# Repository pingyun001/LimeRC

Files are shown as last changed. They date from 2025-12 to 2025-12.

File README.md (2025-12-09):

# LimeRC
数字图传遥控器系统 基于NRF24L01

Digital Video Transmission Remote &amp; Receiver（Based on NRF24L01）
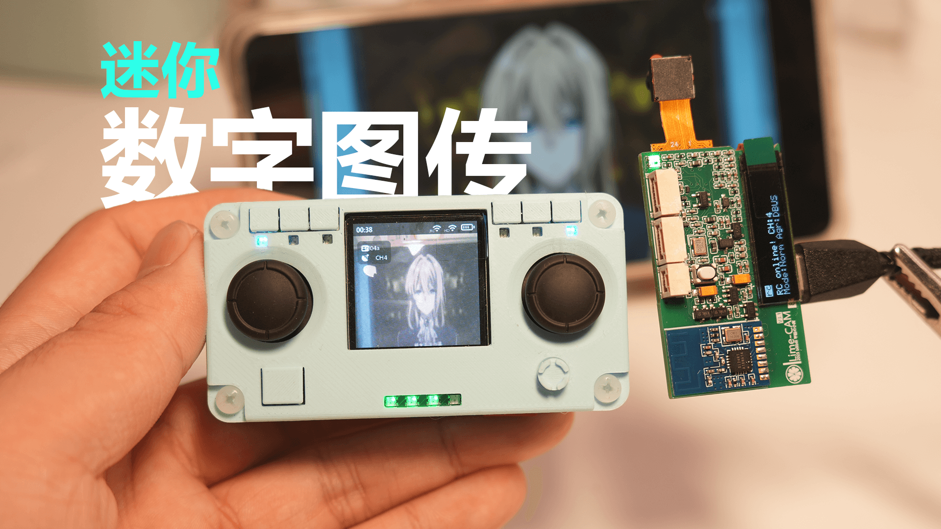
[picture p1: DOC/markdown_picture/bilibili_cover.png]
bilibili_cover


# 详细介绍
> 请跳转立创开源广场查看：
 https://oshwhub.com/phantom001/limerc3-1_release

# 如何获取仓库?

## 使用以下链接获取仓库：

> 遥控器主板程序使用了LVGL Release v9.3，通过submodule的方式引入，请确保使用git clone --recurse-submodules命令克隆仓库。

```
git clone --recurse-submodules https://github.com/pingyun001/LimeRC.git
```
如果已经克隆，可通过如下命令更新submodule：
```
git submodule init
git submodule update
```

## 固件编译

详情参考SOFTWARE文件夹

## 固件下载

推荐使用keil 5MDK 内置下载功能进行下载

若使用CubeProgrammer, 可使用ST-Link配套下载

!!注意 遥控器主板无法通过ST-Link+CubeProgrammer下载，可通过USB下载（按住BOOT键后插入USB到电脑）

# 联系作者

欢迎通过BiliBili私信：
https://space.bilibili.com/336483389

工作忙，尽量24小时内回复

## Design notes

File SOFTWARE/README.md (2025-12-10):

# 文件夹说明
- Lime_SimAgreement：仿真协议，用于测试仿真器与仿真模型的通信协议
- LimeCam_Release：图传接收机源代码
- LimeScrBoard_Release：屏幕按键子板源代码
- LimeMainBoard_Release：遥控器主板源代码
- Z-releaseHex：已编译好的Hex固件
# 编译说明
## Lime_SimAgreement仿真（非必须）
推荐使用VSCode，配置CMake环境+GCC编译
## STM32工程（必须）
- LimeCam_Release
- LimeScrBoard_Release
- LimeMainBoard_Release

推荐使用keil 5MDK编译 需安装如下芯片的keil芯片包
- STM32F0
- STM32F4
- STM32H7

相关芯片包可从keil官网下载 若找不到芯片包，可联系作者获取

推荐keil版本V5.38及以上

注意编译主板固件LimeMainBoard_Release时，需确认lvgl子模块也被克隆

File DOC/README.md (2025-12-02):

# 文件夹说明
## markdown_picture文件夹
> 照片素材，用于本仓库内markdown文件展示

## sdcard_resources文件夹
> 这些图片均由AI生成，仅用于测试机内jpeg软解码器

这些文件可放于SD卡根目录中LimeLvResources文件夹，在点击设置->存储->格式化机内存储时，程序会自动复制这些图片到图库中。

完成后，便可在图库中看到相关图像

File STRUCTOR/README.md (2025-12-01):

# 注意
软件版本为SolidWorks 2025
请使用2025及以上版本打开

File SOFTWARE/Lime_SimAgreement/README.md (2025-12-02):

# 文件夹说明
> 此工程用于软件仿真编解码器

推荐使用VSCode + CMAKE环境编译运行

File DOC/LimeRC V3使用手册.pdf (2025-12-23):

# LimeRC V3使用手册

系统概述：

遥控器操作说明：

遥控器按键说明：

开机说明：

APP选择器说明：

RC遥控APP：

图库APP：

接收机APP：

摇杆校准APP：

设置APP：

接收机 子选项

时间 子选项

屏幕 子选项

存储 子选项

关于 子选项：

接收机操作说明：

LED状态总结：

固件更新：

遥控器主板固件更新：

图传接收机固件更新：

### Mult-Bus输出：

输出电平：

电平正常：

电平取反：

输出协议：

DBUS：

### SBUS：

PP：

DEBUG:

QA：

连接逻辑？

续航&充电？

遥控器卡死了怎么办？

关于

系统由遥控器，接收机两部分组成

# 系统概述：

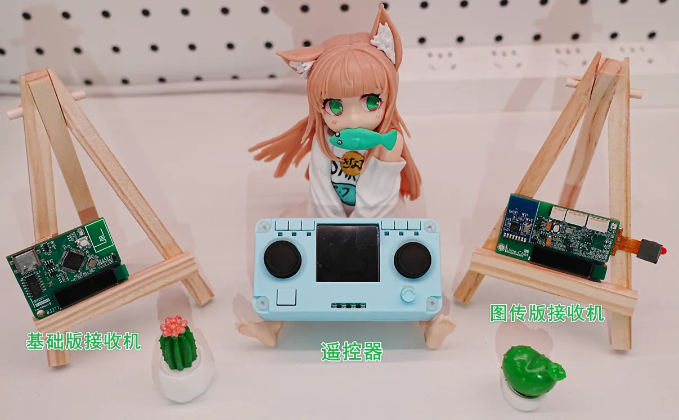
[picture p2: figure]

# 遥控器操作说明：

## 遥控器按键说明：

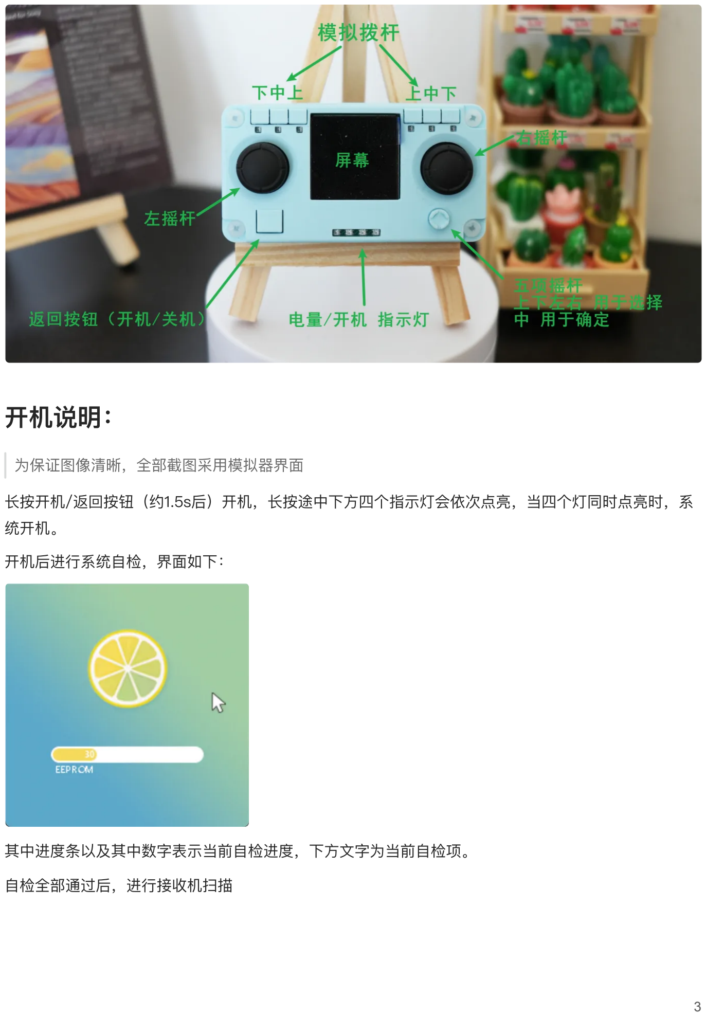
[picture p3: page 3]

长按开机/返回按钮（约1.5s后）开机，长按途中下方四个指示灯会依次点亮，当四个灯同时点亮时，系

统开机。

开机后进行系统自检，界面如下：

其中进度条以及其中数字表示当前自检进度，下方文字为当前自检项。

自检全部通过后，进行接收机扫描

## 开机说明：

为保证图像清晰，全部截图采 | 用模拟器界 | 面

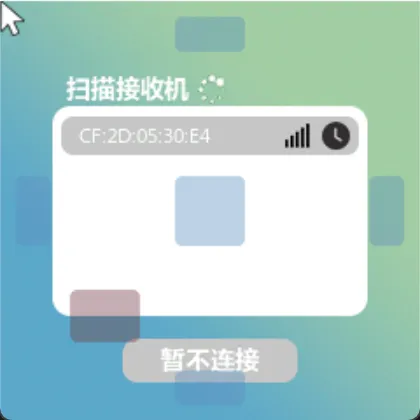
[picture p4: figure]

此界面中可通过五项摇杆“上”、“下”选择需要的接收机，“中”进行选择。

连接完成后点击下一步（后续版本支持多接收机）

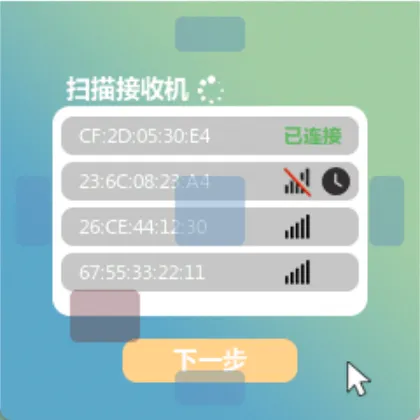
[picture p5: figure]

进入LRC主界面，

顶部状态栏依次为当前时间，遥控器数据下发信号质量，图像回传信号质量，遥控器电量

左侧悬浮窗为接收机名称，接收机所在物理信道。

当前界面中，短按五向摇杆“中”可隐藏UI，短按“右”，可进行拍照（需要连接图传接收机）

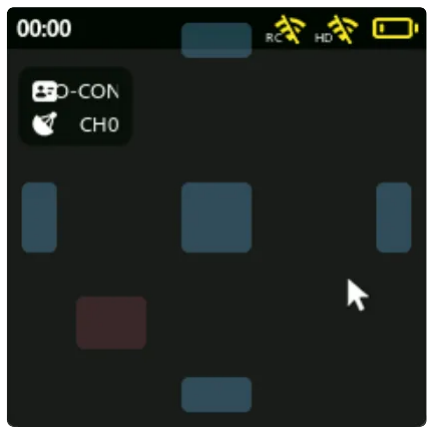
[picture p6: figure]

缺已连接实物图。

长按返回键可退出当前APP：

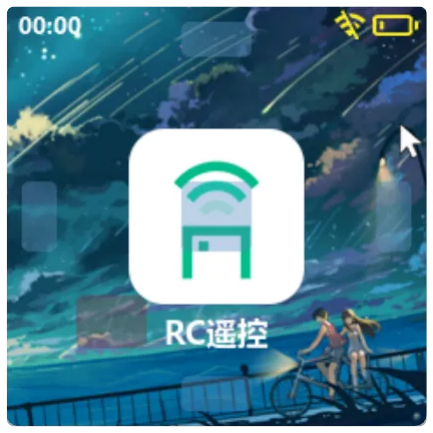
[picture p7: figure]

上述APP为RC遥控APP

APP选择器如下，上方状态栏依次为当前系统时间，遥控器信号质量，遥控器电池信息。

## APP选择器说明：

未连接

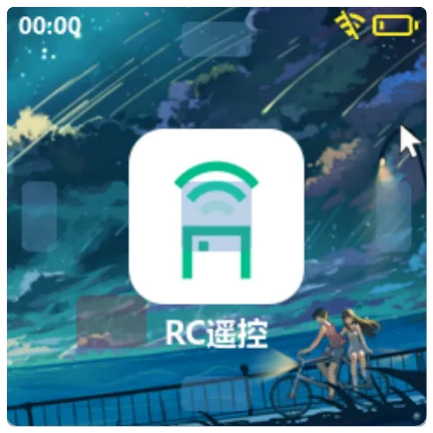
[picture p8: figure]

在该界面下，按下五向摇杆中的“左”或“右”切换APP，按下“中”进入当前APP

V3版本中，APP一共有如下五个：

APP功能如下：

RC遥控：日常操作的主界面，用于观察接收机回传图像，拍照

图库：可以浏览拍到的图像，以及对图像进行删除操作

接收机：为遥控器启动时的对频界面，可以看到当前接收机的连接信息，以及取消配对/配对新接收

机

摇杆校准：校准摇杆零点和极值点，用以补偿摇杆体质不同导致的误差

设置：对遥控器各项功能参数进行设置，详见下文

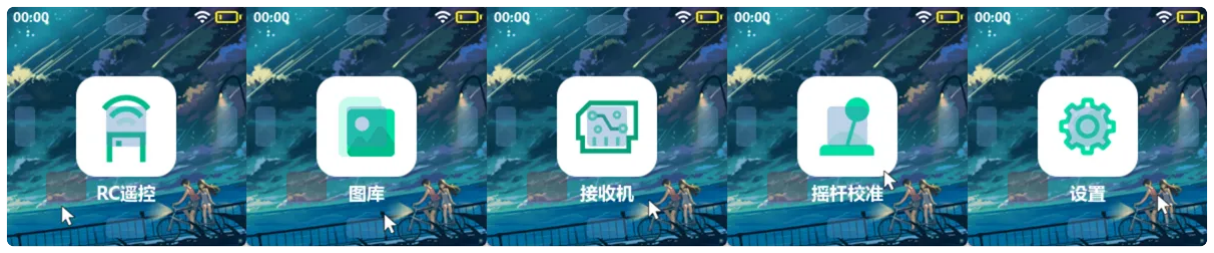
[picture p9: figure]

该APP功能已在上一章 开机说明 中描述，详情看相关章节。

选择&打开图像：

在该APP中，可通过五向摇杆“上”“下”选择图像，点击“中”打开图像，

关闭图像：

在打开图像状态，点击返回关闭图像。

删除图像：

在未打开图像阶段，单击“左”可弹出删除按钮，再次单击“中”，可删除该图像。再次单击“左”，可隐藏

删除按钮。

●

●

●

●

●

### RC遥控APP：

### 图库APP：

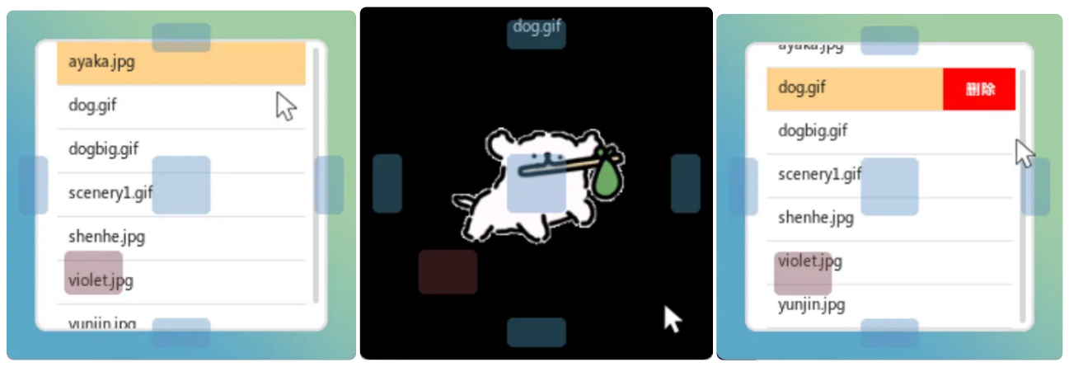
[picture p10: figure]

该APP功能已在上一章 开机说明 中描述，详情看相关章节。

该APP用于自动测量摇杆的中值、死区和边界值，打开后如下：

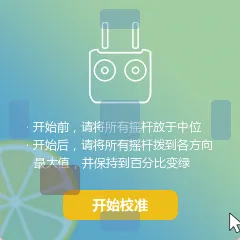
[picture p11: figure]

通过五项摇杆“中”点击开始校准按钮，进入第二界面，

进入第二界面后等待2秒（此两秒用于自动测量中位和死区），

之后将左右两侧摇杆分别推向各个方向最大值并等待2s，待进度百分数变为绿色，则该方向校准完成。

第二界面屏幕显示如下：

## 接收机APP：

## 摇杆校准APP：

！！！注意： | 一定确保两侧摇杆均处于中间位置再进 | 入第 | 二界 | 面
图像选择 | 已经打开的图像 | 图像删除

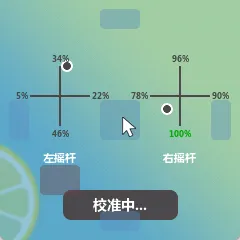
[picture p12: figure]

待完成两个摇杆共8个方向的校准后，下方按钮会变绿，此时可以退出该APP。

校准结果会自动保存到板载EEPROM。

设置APP主界面如下，可通过五向摇杆“上”“下”选择子选项，通过“中”进入子选项。

在子选项中单击返回，可退回设置APP主界面。

每个子选项中，均遵循“上”“下”选择，“中”确定，“返回”返回的逻辑，下文不再赘述。

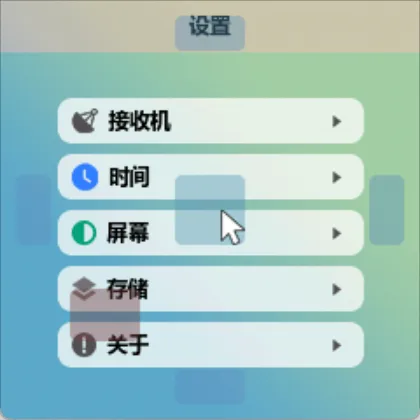
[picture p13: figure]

输出协议：可选DBUS，SBUS，PP，DEBUG。

DBUS：参考DJI DR16接收机输出协议，推荐搭配反向电平使用

### 设置APP：

## 接收机 子选项

●

○

设置APP主界面

SBUS：航模通用协议（待完善）

PP：本作者自有协议，协议帧采用不定长帧，可视化，易于解码。

DEBUG：保留

输出电平：可选正常，反向，静默。

！！！注意！！！

为防止短时期内输出大量不同协议帧到接收机，输出协议和输出电平只有在打开RC遥控APP时才更新到

接收机

另附电平输出样例：（以DBUS，摇杆全归中，三档拨杆下拨）

正常电平：

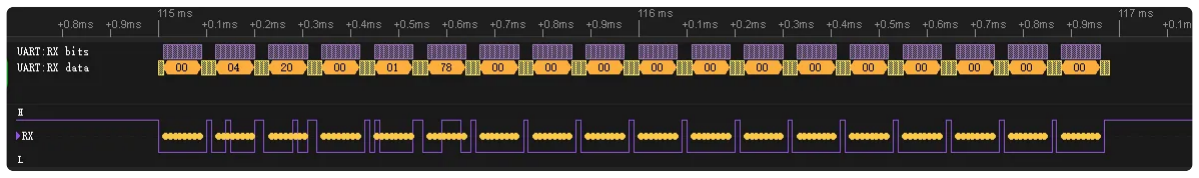
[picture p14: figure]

反向电平：

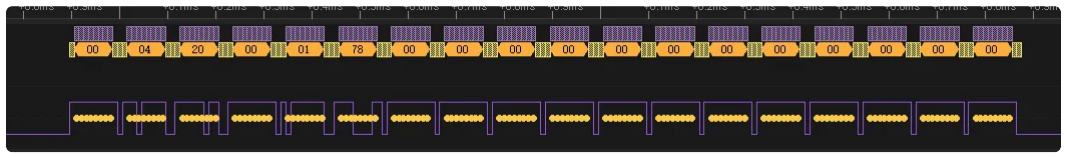
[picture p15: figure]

可设置RTC时间，该时间会用于存储图像以及文件复制时的时间，若不在意可不设置。

○

○

○

●

## 时间 子选项

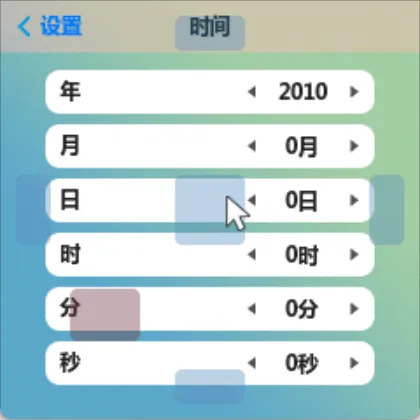
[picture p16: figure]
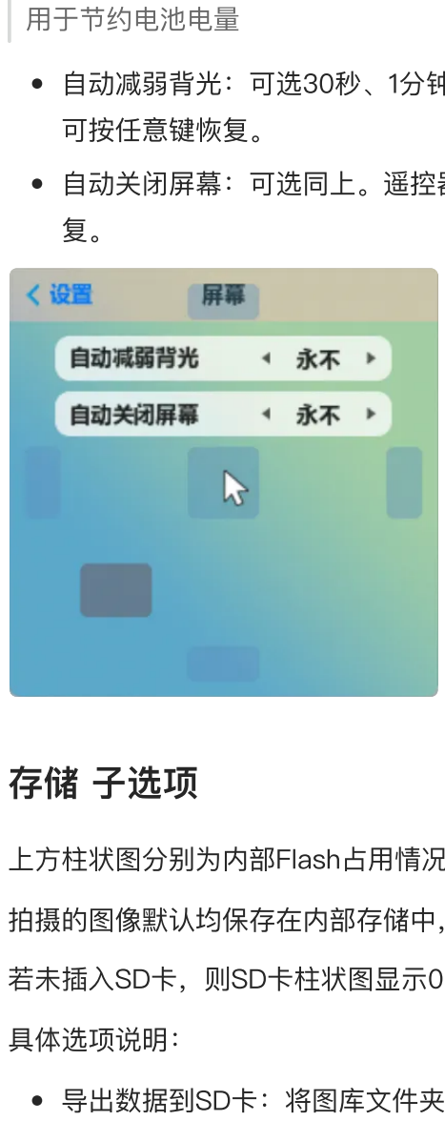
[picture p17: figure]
用于节约电池电量; 存储 子选项

自动减弱背光：可选30秒、1分钟、5分钟、永不。遥控器无操作超过相应时间后，屏幕亮度降低，

可按任意键恢复。

自动关闭屏幕：可选同上。遥控器无操作超过相应时间后，屏幕设定为最低亮度，可按任意键恢

复。

上方柱状图分别为内部Flash占用情况以及外部SD卡占用情况。

拍摄的图像默认均保存在内部存储中，可通过“导出数据到SD卡”选项导出。

若未插入SD卡，则SD卡柱状图显示0

具体选项说明：

导出数据到SD卡：将图库文件夹下的所有文件复制到SD卡。

## 屏幕 子选项

格式化机内存储：清空内部Flash中的图库文件夹。

格式化SD卡：清空SD卡并格式化为FAT32（适用于新SD卡）

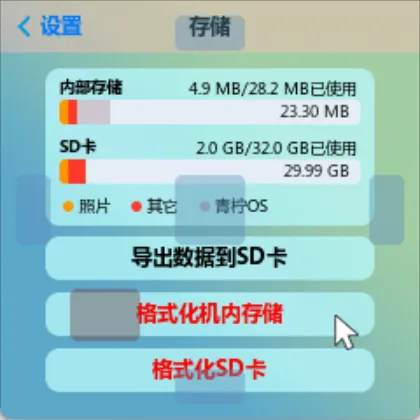
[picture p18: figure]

可查看 产品名称，软硬件版本等相关信息。

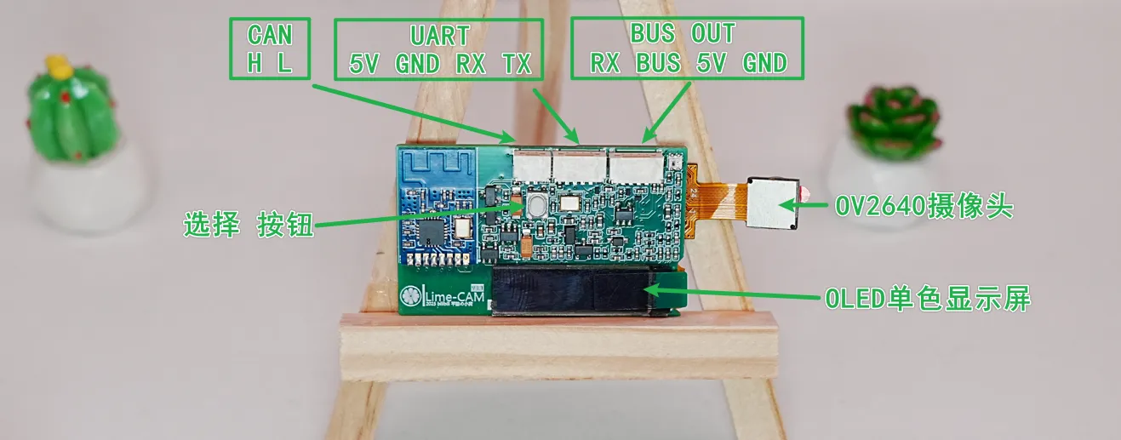
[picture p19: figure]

上电后，通过按钮可选择各个菜单/信息

在RC界面下，长按按钮，可进入配对模式，此时屏幕显示Pairing...，LED亮蓝色。

此时打开遥控器，在遥控器的接收机APP中，可以看到当前处于配对状态的接收机，并选择连接。

连接成功后，接收机亮绿灯，若中途断联，接收机亮红灯。

●

●

## 关于 子选项：

# 接收机操作说明：

蓝灯：接收机处于配对状态

红灯：接收机已有配对信息，但与遥控器断开连接

绿灯：接收机已连接遥控器

遥控器暂时需要拆卸底壳与侧壳，按下BOOT按键后插入USB，以更新固件。

电脑上需安装STM32CubeProgrammer软件：

安装后打开，按住遥控器上的BOOT按键，插入USB到电脑，并进行如下操作：

### LED状态总结：

●

●

●

# 固件更新：

## 遥控器主板固件更新：

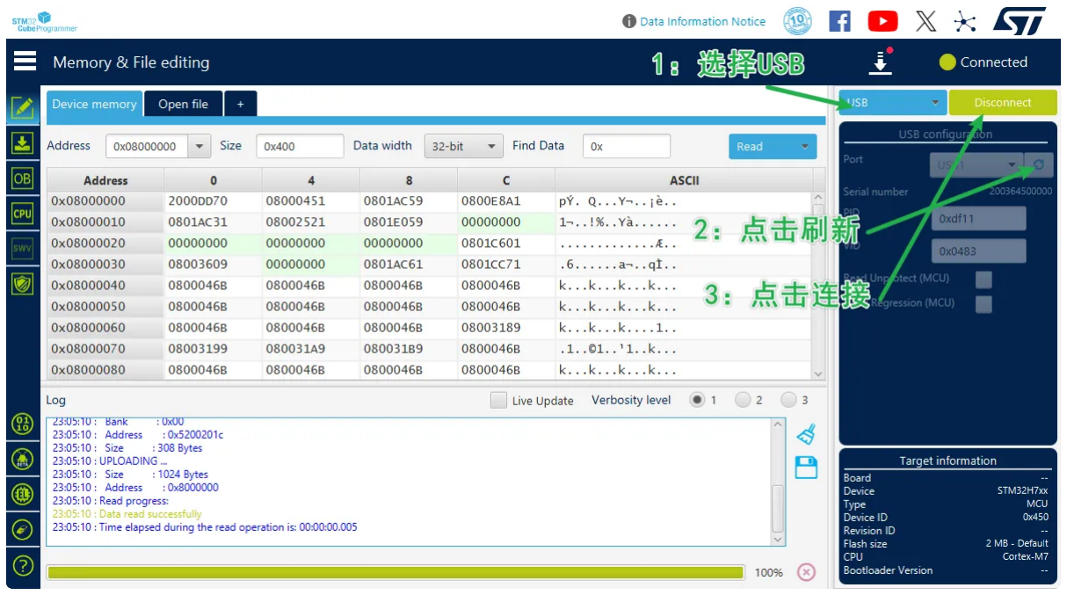
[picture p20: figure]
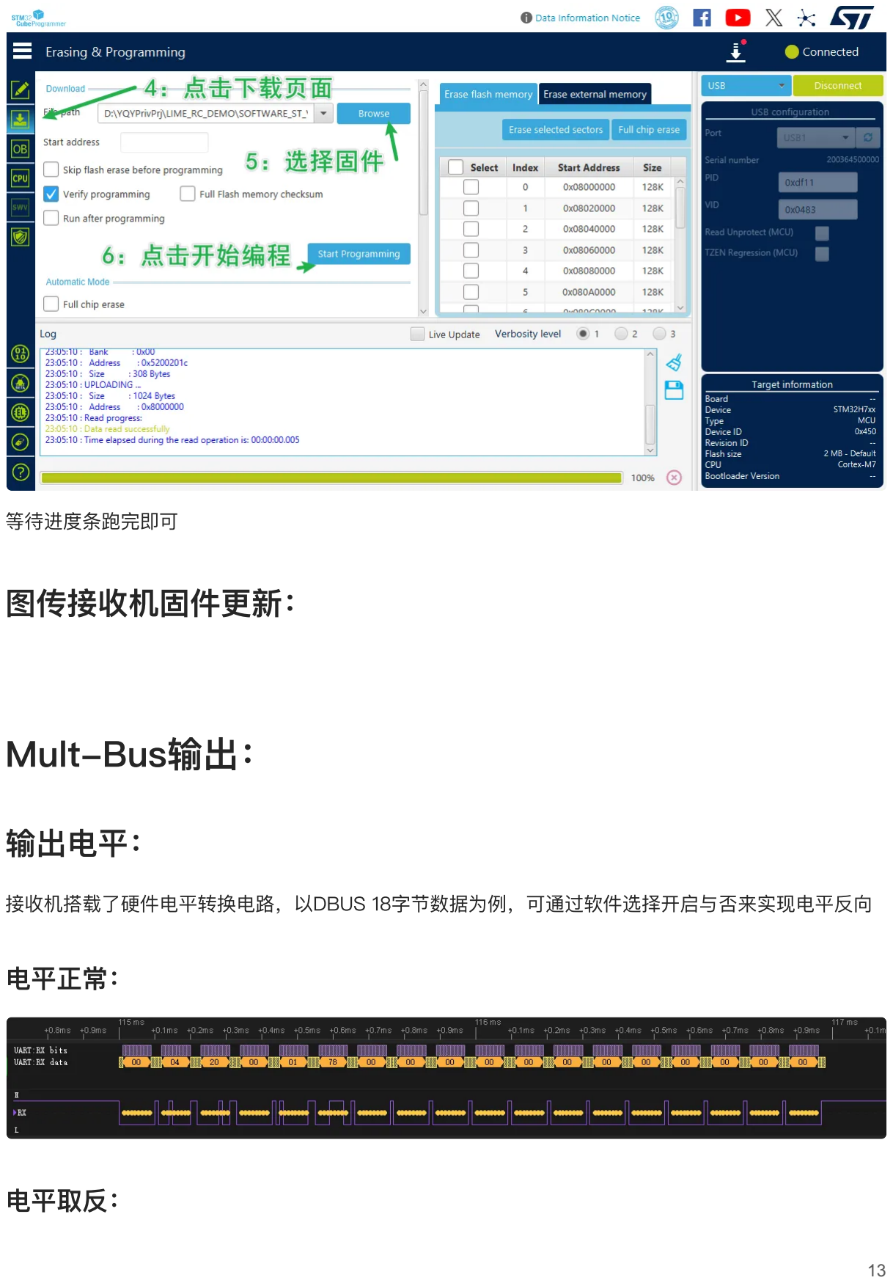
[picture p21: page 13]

等待进度条跑完即可

接收机搭载了硬件电平转换电路，以DBUS 18字节数据为例，可通过软件选择开启与否来实现电平反向

## 图传接收机固件更新：

## Mult-Bus输出：

## 输出电平：

## 电平正常：

## 电平取反：

## 输出协议：

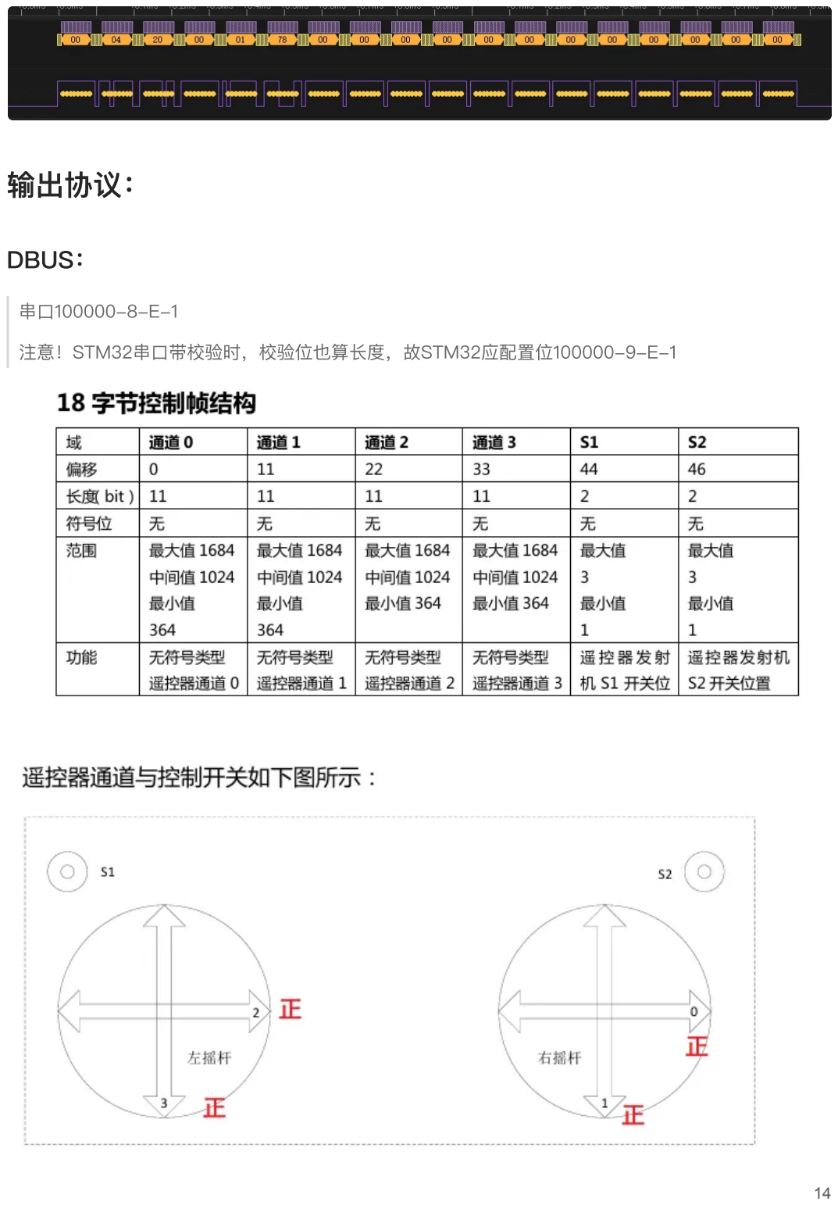
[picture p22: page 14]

DBUS：

# 串口¹⁰⁰⁰⁰⁰⁻⁸⁻E-1

注意！STM32串 | 口带校验时，校验位也算 | 长度，故STM32应配置位100000-9-E-1

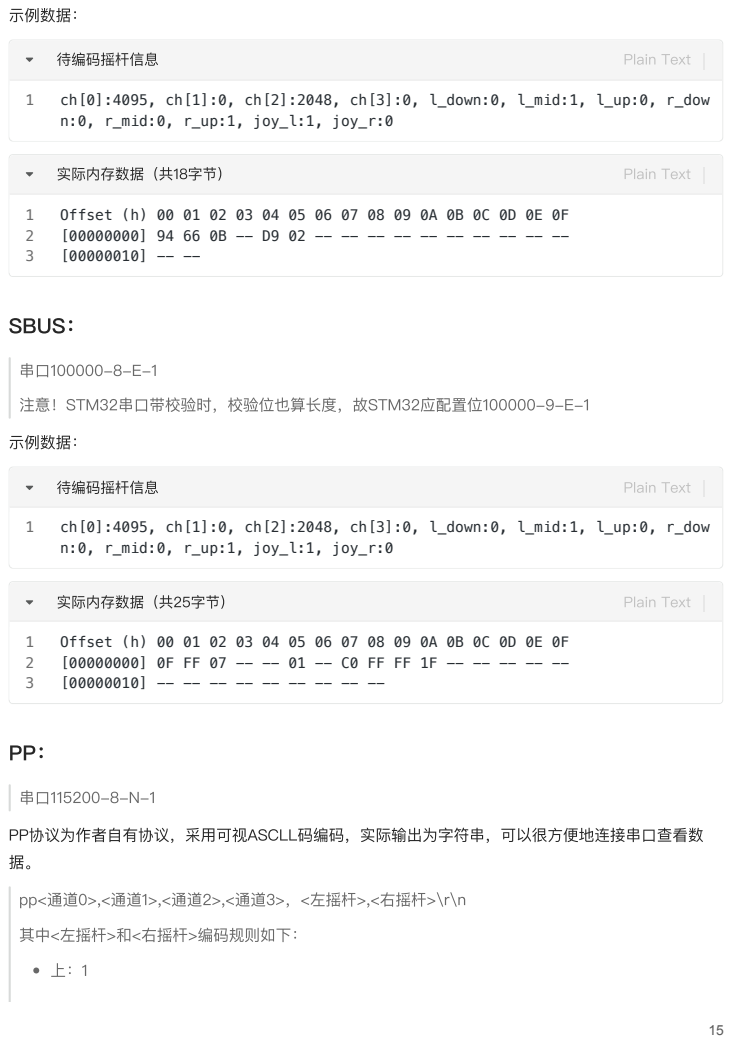
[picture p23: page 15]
示例数据：; SBUS：; 注意！STM32串; 口带校验时，校验位也算; 长度，故STM32应配置位100000-9-E-1; 串口¹¹⁵²⁰⁰⁻⁸⁻N-1; pp<通道0>,<通道1>,<通道2>,<通道3>，<左摇杆>,<右摇杆>\r\n 其中<左摇杆>和<右摇杆>编码规则如下： ●; 待编码摇杆信息; Plain Text; Offset (h) 00 01 02 03 04 05 06 07 08 09 0A 0B 0C 0D 0E 0F [00000000] 94 66 0B -- D9 02 -- -- -- -- -- -- -- -- -- -- [00000010] -- --; 实际内存数据（共18字节）; Offset (h) 00 01 02 03 04 05 06 07 08 09 0A 0B 0C 0D 0E 0F [00000000] 0F FF 07 -- -- 01 -- C0 FF FF 1F -- -- -- -- -- [00000010] -- -- -- -- -- -- -- -- --; 实际内存数据（共25字节）

ch[0]:4095, ch[1]:0, ch[2]:2048, ch[3]:0, l_down:0, l_mid:1, l_up:0, r_dow
n:0, r_mid:0, r_up:1, joy_l:1, joy_r:0
串口¹⁰⁰⁰⁰⁰⁻⁸⁻E-1

PP协议为作者自有协议，采用可视ASCLL码编码，实际输出为字符串，可以很方便地连接串口查看数

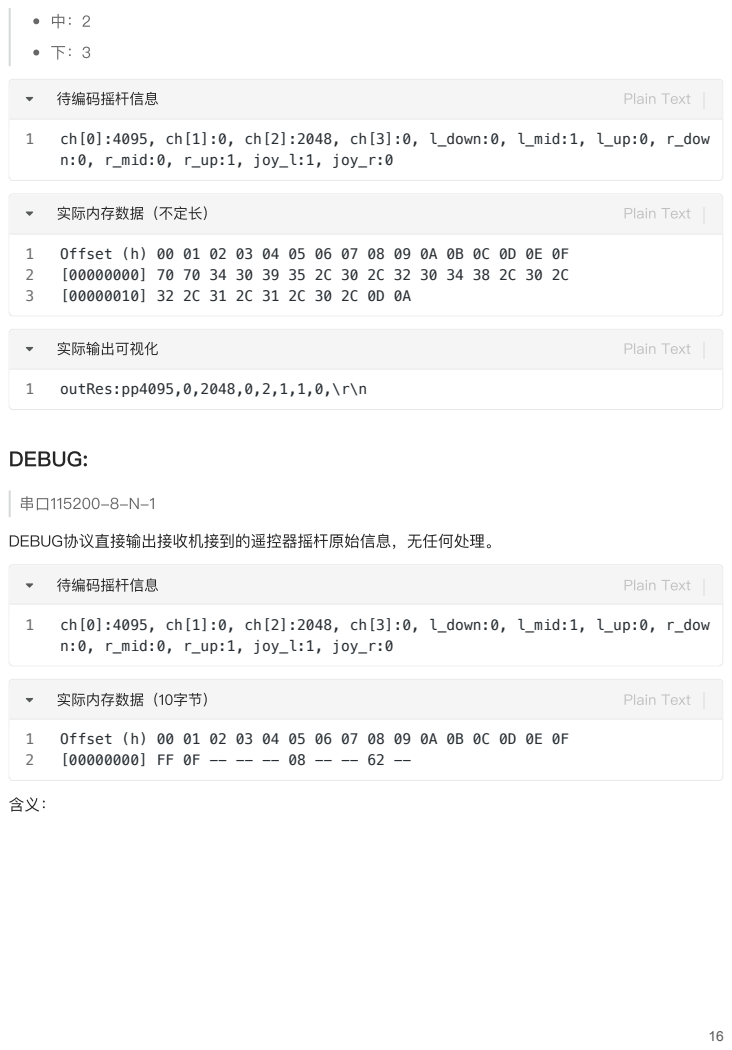
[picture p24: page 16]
DEBUG协议直接输出接收机接到的遥控器摇杆原始信息，无任何处理。; DEBUG: 串口¹¹⁵²⁰⁰⁻⁸⁻N-1; 待编码摇杆信息; Plain Text; Offset (h) 00 01 02 03 04 05 06 07 08 09 0A 0B 0C 0D 0E 0F [00000000] 70 70 34 30 39 35 2C 30 2C 32 30 34 38 2C 30 2C [00000010] 32 2C 31 2C 31 2C 30 2C 0D 0A; 实际内存数据（不定长）; 1 outRes:pp4095,0,2048,0,2,1,1,0,\r\n; 实际输出可视化; Offset (h) 00 01 02 03 04 05 06 07 08 09 0A 0B 0C 0D 0E 0F [00000000] FF 0F -- -- -- 08 -- -- 62 --; 实际内存数据（10字节）

ch[0]:4095, ch[1]:0, ch[2]:2048, ch[3]:0, l_down:0, l_mid:1, l_up:0, r_dow
n:0, r_mid:0, r_up:1, joy_l:1, joy_r:0

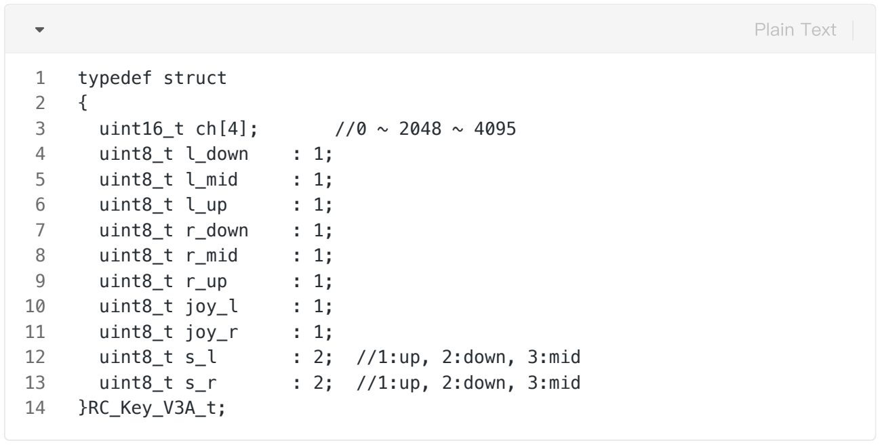
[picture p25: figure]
typedef struct {; uint16_t ch[4];; uint8_t l_down; uint8_t l_mid; uint8_t l_up; uint8_t r_down; uint8_t r_mid; uint8_t r_up; uint8_t joy_l; uint8_t joy_r; uint8_t s_l; : 2; //1:up, 2:down, 3:mid; uint8_t s_r; }RC_Key_V3A_t;; Plain Text

当某个遥控器与某个接收机成功进行一次配对后，遥控器和接收机均会记忆对方信息，以便于：

1. 下次上电后自动连接
2. 某一 方突然掉线/断连 后 的自动重新连接

续航约3h，充电约需要2.5h

遥控器设置了看门狗，超时时间为9秒，若遥控器卡死（部分任务卡死 且以正常方式触发关机无效），

可通过长按返回按钮10秒以上，进而强制复位整个遥控器系统。

QA：

## 连接逻辑？

## 续航&充电？

## 遥控器卡死了怎么办？

2025 bilibili 平韵の小窝 版权所有

关于

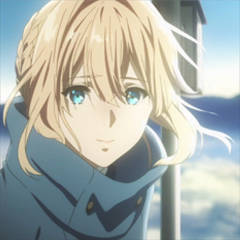
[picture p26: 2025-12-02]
DOC/sdcard_resources/Violet.jpg

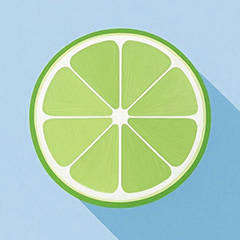
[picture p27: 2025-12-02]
DOC/sdcard_resources/greenLemon.jpg

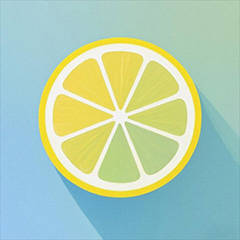
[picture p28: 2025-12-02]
DOC/sdcard_resources/yellowLemon.jpg

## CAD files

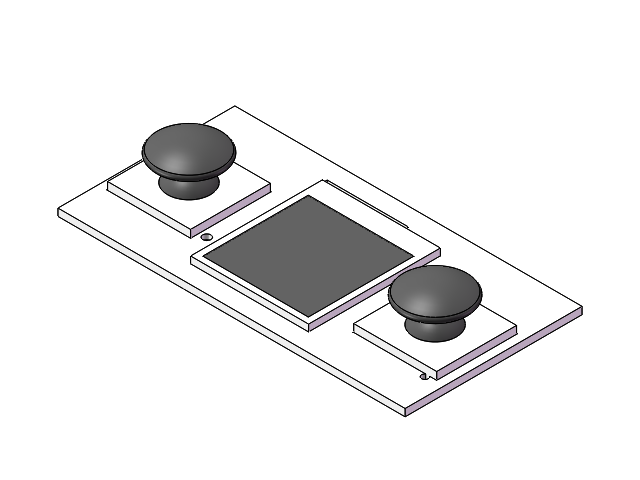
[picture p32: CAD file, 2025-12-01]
STRUCTOR/ScreenSubBoard/装配体1.SLDASM
1.3寸240屏幕焊接
3D摇杆 x 2
PCB定位件

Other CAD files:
STRUCTOR/RemoteController/PCB零件/U2~SOT-23-3_L2.9-W1.6-P1.90-LS2.8-BR~SOT-23-3L_L2.9-W1.6-H1.1-LS2.8-P0.95~6X63_1.step.SLDASM
STRUCTOR/RemoteController/PCB零件/RN1~RES-ARRAY-SMD_0603-8P-L3.2-W1.6-BL~R0603-8P_L3.2-W1.6-H0.6~6X63_1.step.SLDASM
STRUCTOR/RemoteController/PCB零件/KEY1~SW-SMD_4P-L4.2-W3.3-P2.15-LS5.1~SW-SMD_4P-L4.2-W3.3-H2.5-P2.15-LS5.1~6X63_1.step.SLDASM
STRUCTOR/RemoteController/PCB零件/LED1~LED0603-RD~LED0603-RD~6X63_1.step.SLDASM
STRUCTOR/RemoteController/PCB零件/U16~SW-SMD_WS-1002-ACW05026~SW-SMD_TM-4175-B-X~6X63_1.step.SLDASM
STRUCTOR/RemoteController/PCB零件/C1~C0402~C0402_L1.0-W0.5-H0.5~6X63_1.step.SLDASM
STRUCTOR/RemoteController/PCB零件/Q1~SOT-23_L2.9-W1.3-P1.90-LS2.4-BR~SOT-23-3P_L2.9-W1.3-H1.0-LS2.4-P0.95~6X63_1.step.SLDASM
STRUCTOR/RemoteController/PCB零件/FPC1~FPC-SMD_P0.50-6P_QCHF-SM-H2.0_1~PFC-SMD_P0.50-6P_QCHF-SM-H2.0~6X63_1.step.SLDASM
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

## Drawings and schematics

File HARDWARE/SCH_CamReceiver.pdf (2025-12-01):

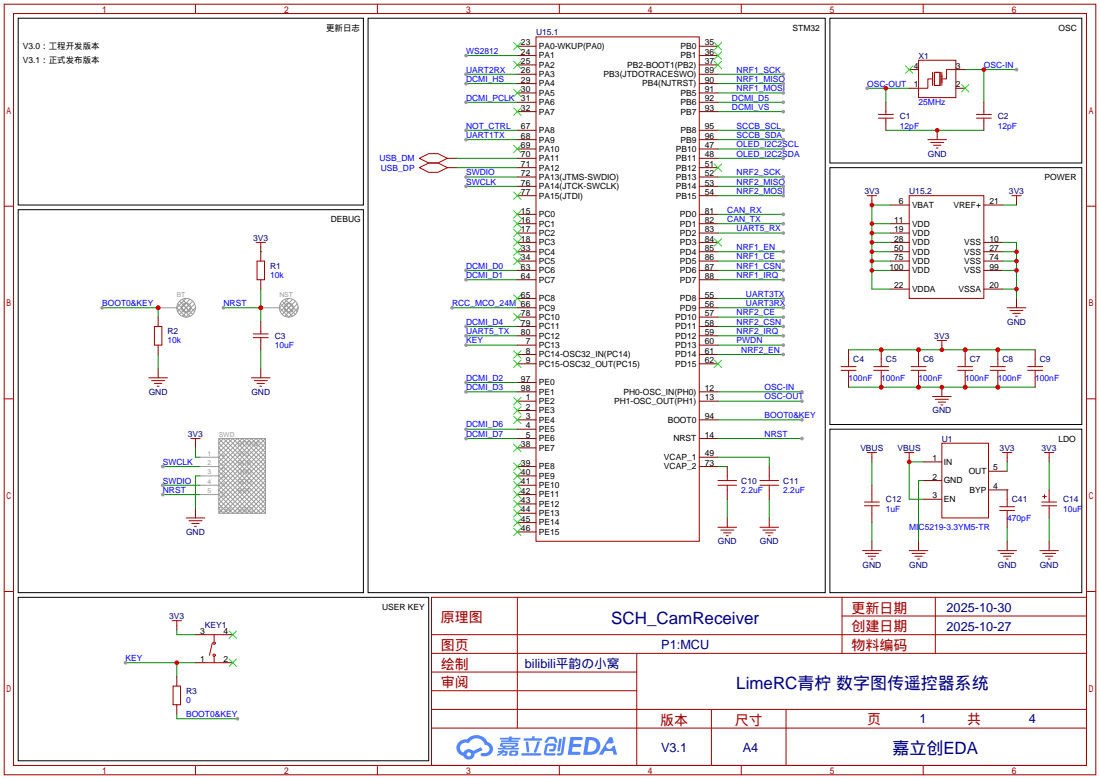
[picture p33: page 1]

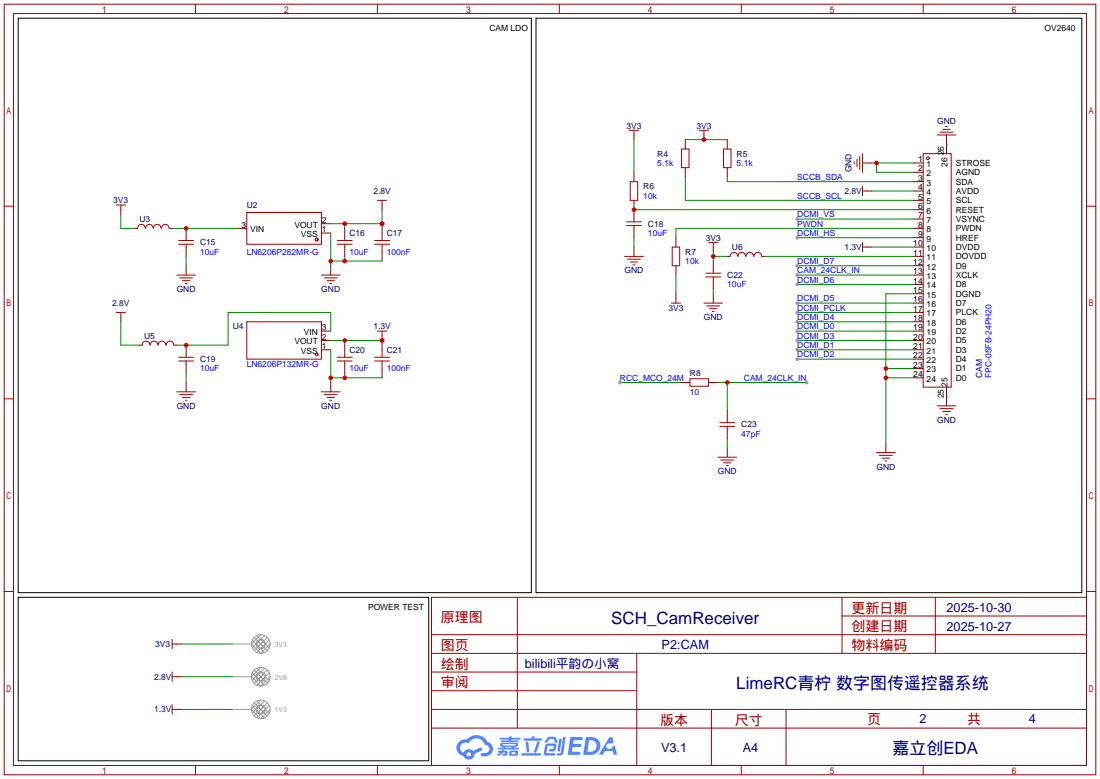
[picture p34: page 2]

### AS01-ML01S

# DEBUSGH¹²⁵⁻S⁰⁴DCA⁻⁰⁰

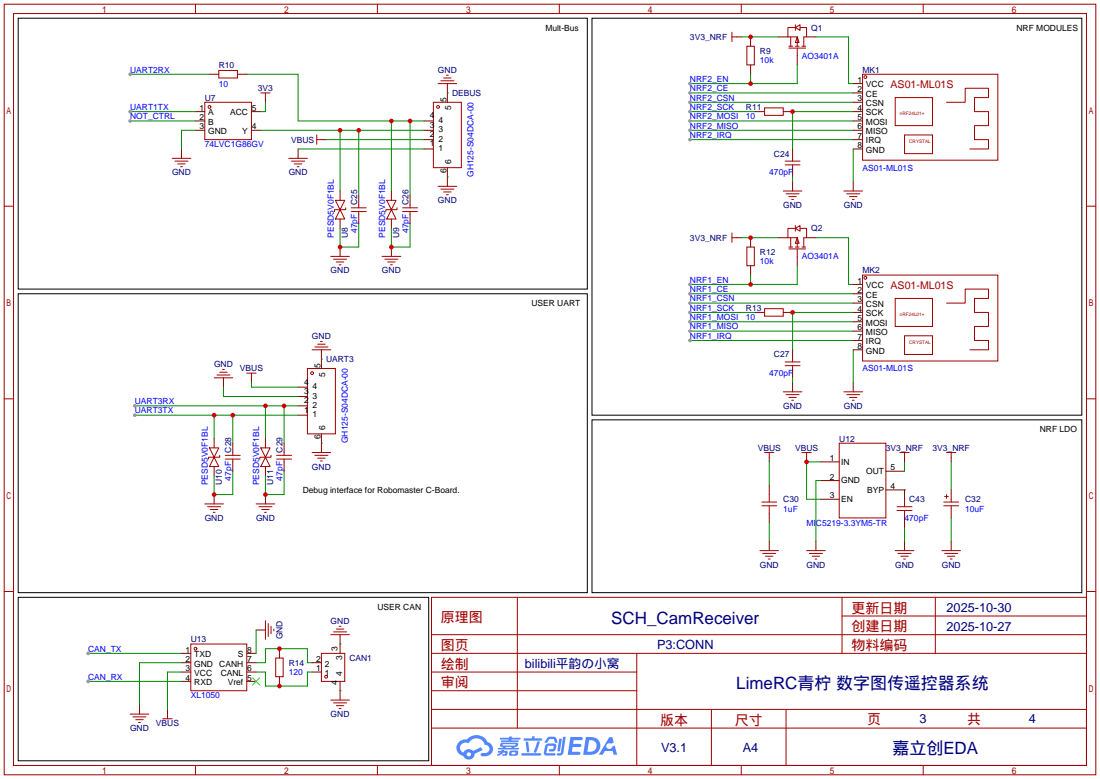
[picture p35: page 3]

Debug interface for Robomaster C-Board.

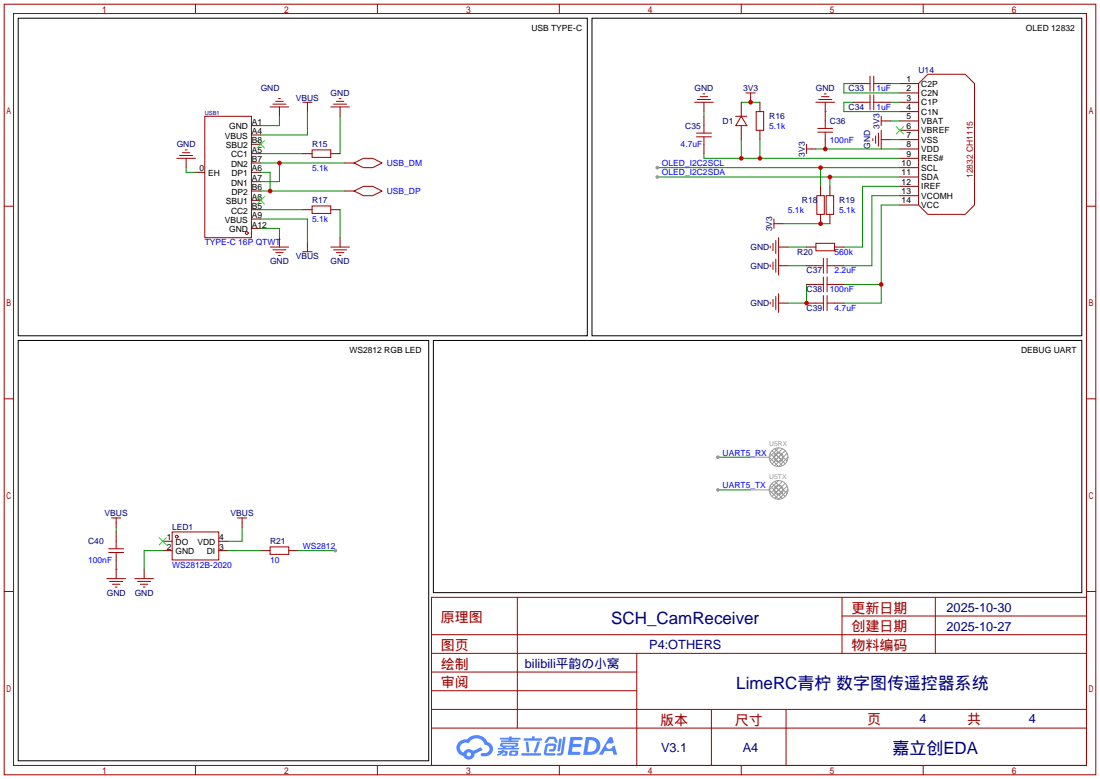
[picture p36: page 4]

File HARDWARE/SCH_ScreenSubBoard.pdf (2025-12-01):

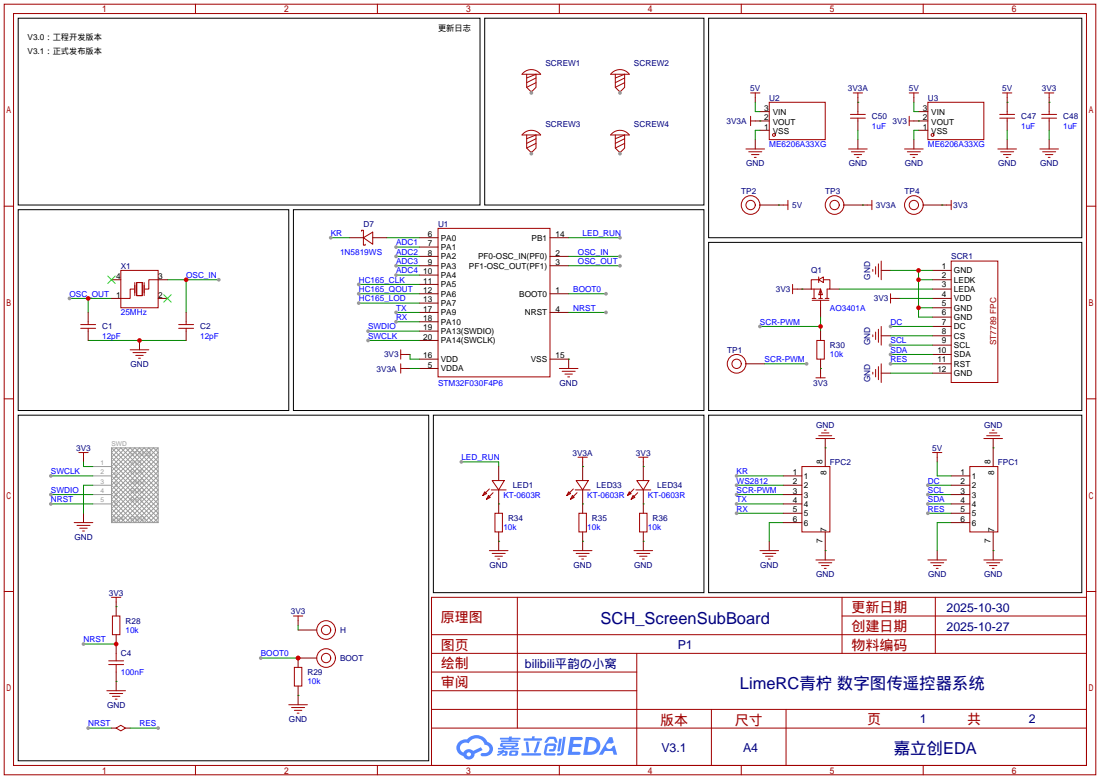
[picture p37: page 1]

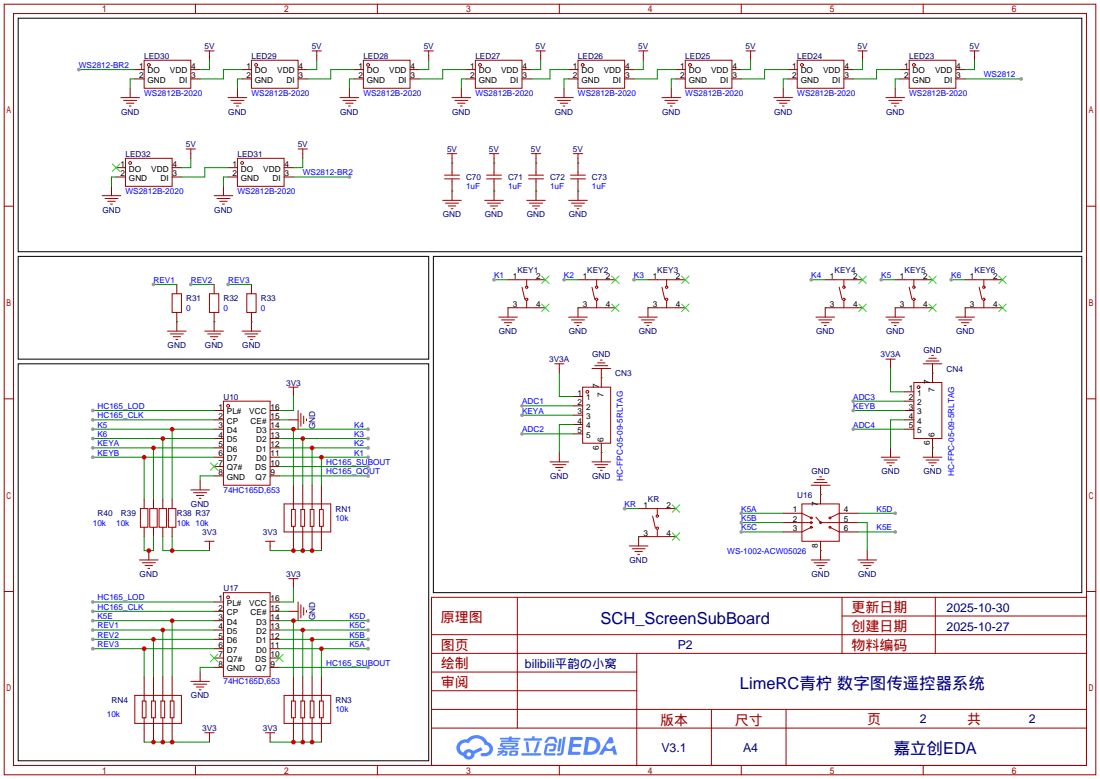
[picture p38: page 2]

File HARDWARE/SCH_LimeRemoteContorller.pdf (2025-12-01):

VDD 50 PB12 51 PB13 52 PB14 53 PB15 54 PD8 55 PD9 56 PD10 57 PD11 58 PD12 59 PD13 60 PD14 61 PD15 62 PC6 63 PC7 64 PC8 65 PC9 66 PA8 67 PA9 68 PA10 69 PA11 70 PA12 71 PA13 72 VCAP 73 VSS 74 VDD 75 PA14 76 PA15 77 PC10 78 PC11 79 PC12 80 PD0 81 PD1 82 PD2 83 PD3 84 PD4 85 PD5 86 PD6 87 PD7 88 PB3 89 PB4 90 PB5 91 PB6 92 PB7 93 BOOT0 94 PB8 95 PB9 96 PE0 97 PE1 98 VSS 99 VDD 100

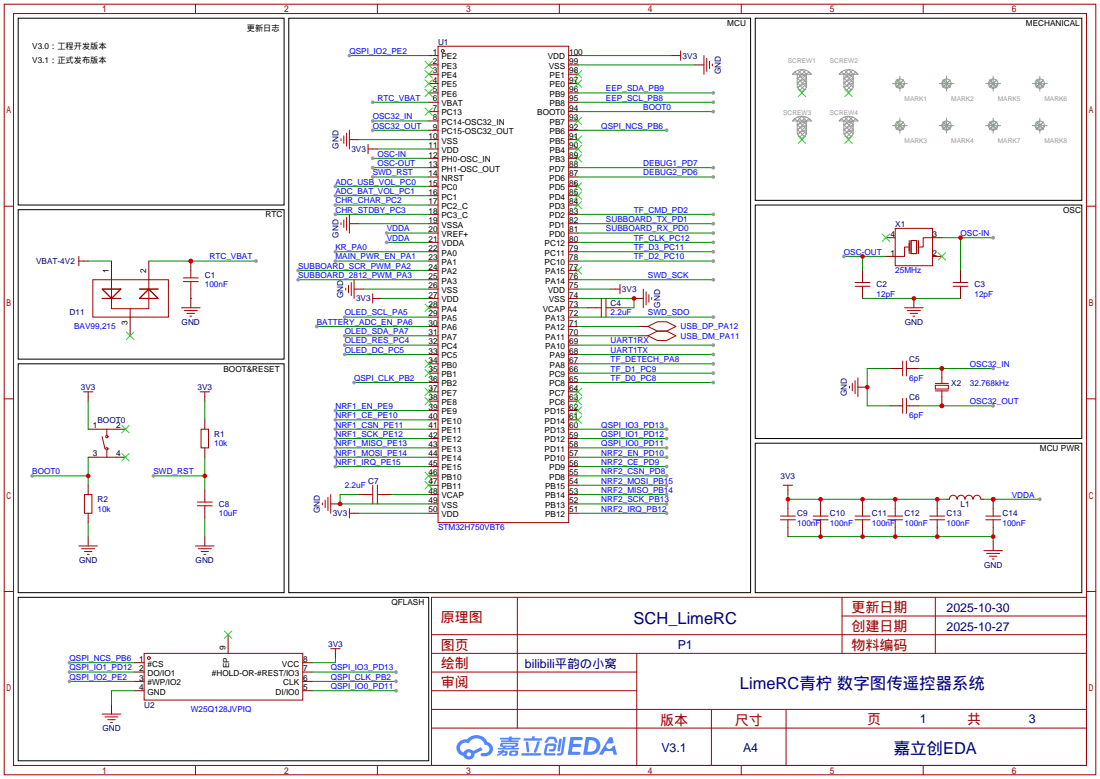
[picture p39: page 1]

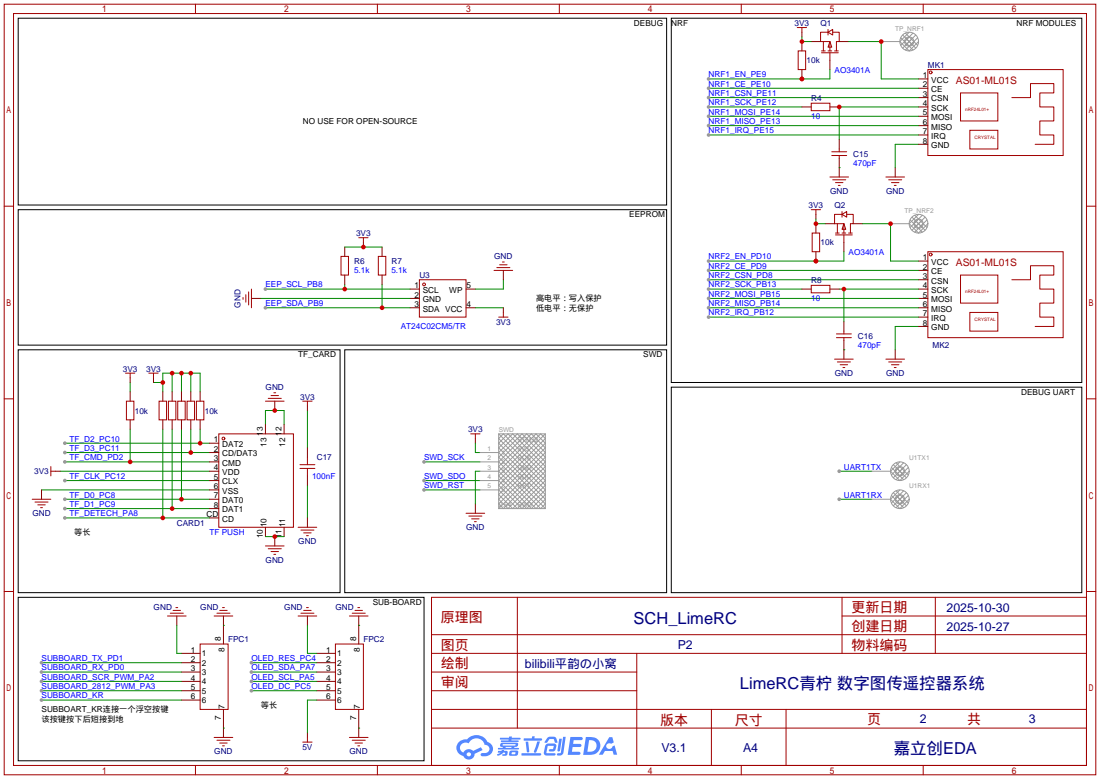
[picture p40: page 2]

NO USE FOR OPEN-SOURCE

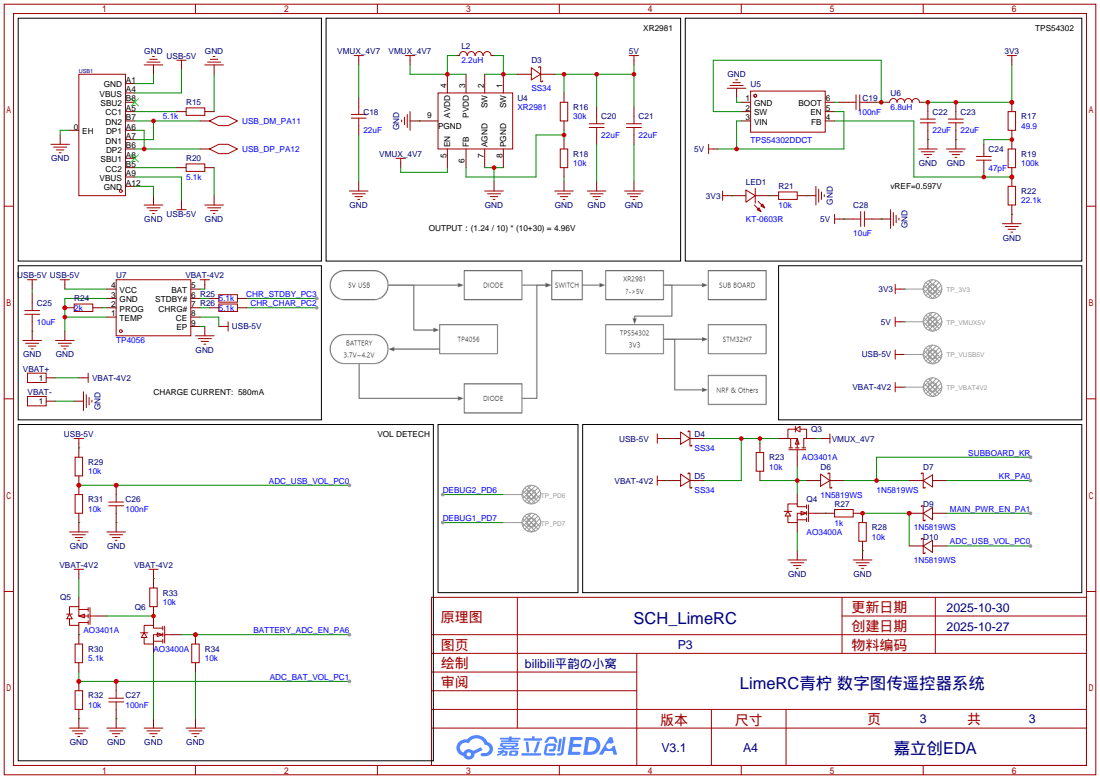
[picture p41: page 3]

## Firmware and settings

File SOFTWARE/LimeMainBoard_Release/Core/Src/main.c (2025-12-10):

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
/* Includes ------------------------------------------------------------------*/
#include "main.h"
#include "cmsis_os.h"
#include "adc.h"
#include "crc.h"
#include "dma.h"
#include "dma2d.h"
#include "i2c.h"
#include "iwdg.h"
#include "jpeg.h"
#include "mdma.h"
#include "memorymap.h"
#include "quadspi.h"
#include "rtc.h"
#include "sdmmc.h"
#include "spi.h"
#include "tim.h"
#include "usart.h"
#include "gpio.h"

/* USER CODE BEGIN Includes */
#include "ws2812.h"
/* USER CODE END Includes */


void SystemClock_Config(void);
void PeriphCommonClock_Config(void);
static void MPU_Config(void);
void MX_FREERTOS_Init(void);
/**
  * @brief  The application entry point.
  * @retval int
  */
int main(void)
{

  /* MPU Configuration--------------------------------------------------------*/
  MPU_Config();

  /* Enable the CPU Cache */

  /* Enable I-Cache---------------------------------------------------------*/
  SCB_EnableICache();

  /* Enable D-Cache---------------------------------------------------------*/
  SCB_EnableDCache();

  /* MCU Configuration--------------------------------------------------------*/

  /* Reset of all peripherals, Initializes the Flash interface and the Systick. */
  HAL_Init();

  /* Configure the system clock */
  SystemClock_Config();

  /* Configure the peripherals common clocks */
  PeriphCommonClock_Config();

  /* Initialize all configured peripherals */
  MX_GPIO_Init();
  MX_MDMA_Init();
  MX_DMA_Init();
  MX_USART1_UART_Init();
  MX_QUADSPI_Init();
  MX_SDMMC1_SD_Init();
  MX_SPI2_Init();
  MX_TIM5_Init();
  MX_SPI1_Init();
  MX_UART4_Init();
  MX_RTC_Init();
  MX_CRC_Init();
  MX_JPEG_Init();
  MX_DMA2D_Init();
  MX_SPI4_Init();
  MX_I2C1_Init();
  MX_ADC1_Init();
  MX_ADC2_Init();
  MX_TIM15_Init();
  MX_IWDG1_Init();
  /* USER CODE BEGIN 2 */
	
	LEprintf("\n\nLime RC V3.1 demo,Start!\n");
	LEprintf("CompileTime:%s,%s\n", __DATE__, __TIME__);
	
	/* enable main power	*/
	HAL_GPIO_WritePin(MAIN_PWR_GPIO_Port, MAIN_PWR_Pin, GPIO_PIN_RESET);
	
	/* Init WS2812 */
	ws2812_Init();
	
	while(1)
	{
		static uint32_t kr_release_time = 0;
		
		if(!IS_KR_PRESSED())
		{
			kr_release_time = HAL_GetTick();
			WS2812_SetPowerOnSequence(0);
		}
		
		if(IS_KR_PRESSED())
		{
			if(HAL_GetTick() - kr_release_time < 100)
				WS2812_SetPowerOnSequence(0);
			else if(HAL_GetTick() - kr_release_time < 400)
				WS2812_SetPowerOnSequence(1);
			else if(HAL_GetTick() - kr_release_time < 700)
				WS2812_SetPowerOnSequence(2);
			else if(HAL_GetTick() - kr_release_time < 1000)
				WS2812_SetPowerOnSequence(3);
			else if(HAL_GetTick() - kr_release_time < 1200)
				WS2812_SetPowerOnSequence(4);
			else
			{
				HAL_GPIO_WritePin(MAIN_PWR_GPIO_Port, MAIN_PWR_Pin, GPIO_PIN_SET);
				break;
			}
			
			/* feed watchdog */
			HAL_IWDG_Refresh(&hiwdg1);
		}
	}
	
	/* enable main power */
	HAL_GPIO_WritePin(MAIN_PWR_GPIO_Port, MAIN_PWR_Pin, GPIO_PIN_SET);
	

  /* USER CODE END 2 */

  /* Call init function for freertos objects (in cmsis_os2.c) */
  MX_FREERTOS_Init();

  /* Start scheduler */
  osKernelStart();

  /* We should never get here as control is now taken by the scheduler */

  /* Infinite loop */
  /* USER CODE BEGIN WHILE */
  while (1)
  {
    /* USER CODE END WHILE */

    /* USER CODE BEGIN 3 */
  }
  /* USER CODE END 3 */
}

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
 /* MPU Configuration */

void MPU_Config(void)
{
  MPU_Region_InitTypeDef MPU_InitStruct = {0};

  /* Disables the MPU */
  HAL_MPU_Disable();

  /** Initializes and configures the Region and the memory to be protected
  */
  MPU_InitStruct.Enable = MPU_REGION_ENABLE;
  MPU_InitStruct.Number = MPU_REGION_NUMBER0;
  MPU_InitStruct.BaseAddress = 0x0;
  MPU_InitStruct.Size = MPU_REGION_SIZE_4GB;
  MPU_InitStruct.SubRegionDisable = 0x87;
  MPU_InitStruct.TypeExtField = MPU_TEX_LEVEL0;
  MPU_InitStruct.AccessPermission = MPU_REGION_NO_ACCESS;
  MPU_InitStruct.DisableExec = MPU_INSTRUCTION_ACCESS_DISABLE;
  MPU_InitStruct.IsShareable = MPU_ACCESS_SHAREABLE;
  MPU_InitStruct.IsCacheable = MPU_ACCESS_NOT_CACHEABLE;
  MPU_InitStruct.IsBufferable = MPU_ACCESS_NOT_BUFFERABLE;

  HAL_MPU_ConfigRegion(&MPU_InitStruct);

  /** Initializes and configures the Region and the memory to be protected
  */
  MPU_InitStruct.Number = MPU_REGION_NUMBER1;
  MPU_InitStruct.BaseAddress = 0x08000000;
  MPU_InitStruct.Size = MPU_REGION_SIZE_2MB;
  MPU_InitStruct.SubRegionDisable = 0x0;
  MPU_InitStruct.TypeExtField = MPU_TEX_LEVEL1;
  MPU_InitStruct.AccessPermission = MPU_REGION_PRIV_RO_URO;
  MPU_InitStruct.DisableExec = MPU_INSTRUCTION_ACCESS_ENABLE;
  MPU_InitStruct.IsShareable = MPU_ACCESS_NOT_SHAREABLE;
  MPU_InitStruct.IsCacheable = MPU_ACCESS_CACHEABLE;
  MPU_InitStruct.IsBufferable = MPU_ACCESS_BUFFERABLE;

  HAL_MPU_ConfigRegion(&MPU_InitStruct);

  /** Initializes and configures the Region and the memory to be protected
  */
  MPU_InitStruct.Number = MPU_REGION_NUMBER2;
  MPU_InitStruct.BaseAddress = 0x24000000;
  MPU_InitStruct.Size = MPU_REGION_SIZE_512KB;
  MPU_InitStruct.AccessPermission = MPU_REGION_FULL_ACCESS;

  HAL_MPU_ConfigRegion(&MPU_InitStruct);

  /** Initializes and configures the Region and the memory to be protected
  */
  MPU_InitStruct.Number = MPU_REGION_NUMBER3;
  MPU_InitStruct.BaseAddress = 0x30000000;
  MPU_InitStruct.Size = MPU_REGION_SIZE_256KB;

  HAL_MPU_ConfigRegion(&MPU_InitStruct);

  /** Initializes and configures the Region and the memory to be protected
  */
  MPU_InitStruct.Number = MPU_REGION_NUMBER4;
  MPU_InitStruct.BaseAddress = 0x30040000;
  MPU_InitStruct.Size = MPU_REGION_SIZE_32KB;
  MPU_InitStruct.TypeExtField = MPU_TEX_LEVEL0;
  MPU_InitStruct.DisableExec = MPU_INSTRUCTION_ACCESS_DISABLE;
  MPU_InitStruct.IsCacheable = MPU_ACCESS_NOT_CACHEABLE;
  MPU_InitStruct.IsBufferable = MPU_ACCESS_NOT_BUFFERABLE;

  HAL_MPU_ConfigRegion(&MPU_InitStruct);

  /** Initializes and configures the Region and the memory to be protected
  */
  MPU_InitStruct.Number = MPU_REGION_NUMBER5;
  MPU_InitStruct.BaseAddress = 0x38000000;
  MPU_InitStruct.Size = MPU_REGION_SIZE_64KB;
  MPU_InitStruct.DisableExec = MPU_INSTRUCTION_ACCESS_ENABLE;

  HAL_MPU_ConfigRegion(&MPU_InitStruct);

  /** Initializes and configures the Region and the memory to be protected
  */
  MPU_InitStruct.Number = MPU_REGION_NUMBER6;
  MPU_InitStruct.BaseAddress = 0x20000000;
  MPU_InitStruct.Size = MPU_REGION_SIZE_128KB;
  MPU_InitStruct.TypeExtField = MPU_TEX_LEVEL1;
  MPU_InitStruct.IsCacheable = MPU_ACCESS_CACHEABLE;
  MPU_InitStruct.IsBufferable = MPU_ACCESS_BUFFERABLE;

  HAL_MPU_ConfigRegion(&MPU_InitStruct);

  /** Initializes and configures the Region and the memory to be protected
  */
  MPU_InitStruct.Number = MPU_REGION_NUMBER7;
  MPU_InitStruct.BaseAddress = 0x40000000;
  MPU_InitStruct.Size = MPU_REGION_SIZE_256MB;
  MPU_InitStruct.TypeExtField = MPU_TEX_LEVEL0;
  MPU_InitStruct.IsCacheable = MPU_ACCESS_NOT_CACHEABLE;
  MPU_InitStruct.IsBufferable = MPU_ACCESS_NOT_BUFFERABLE;

  HAL_MPU_ConfigRegion(&MPU_InitStruct);
  /* Enables the MPU */
  HAL_MPU_Enable(MPU_PRIVILEGED_DEFAULT);

}

/**
  * @brief  Period elapsed callback in non blocking mode
  * @note   This function is called  when TIM17 interrupt took place, inside
  * HAL_TIM_IRQHandler(). It makes a direct call to HAL_IncTick() to increment
  * a global variable "uwTick" used as application time base.
  * @param  htim : TIM handle
  * @retval None
  */
void HAL_TIM_PeriodElapsedCallback(TIM_HandleTypeDef *htim)
{
  if (htim->Instance == TIM17) {
    HAL_IncTick();
  }
}

/**
  * @brief  This function is executed in case of error occurrence.
  * @retval None
  */
void Error_Handler(void)
{
  /* USER CODE BEGIN Error_Handler_Debug */
	LEprintf("%s()\n", __FUNCTION__);
  /* User can add his own implementation to report the HAL error return state */
  __disable_irq();
  while (1)
  {
  }
  /* USER CODE END Error_Handler_Debug */
}

#ifdef  USE_FULL_ASSERT
/**
  * @brief  Reports the name of the source file and the source line number
  *         where the assert_param error has occurred.
  * @param  file: pointer to the source file name
  * @param  line: assert_param error line source number
  * @retval None
  */
void assert_failed(uint8_t *file, uint32_t line)
{
  /* USER CODE BEGIN 6 */
  /* User can add his own implementation to report the file name and line number,
     ex: printf("Wrong parameters value: file %s on line %d\r\n", file, line) */
  /* USER CODE END 6 */
}
#endif /* USE_FULL_ASSERT */

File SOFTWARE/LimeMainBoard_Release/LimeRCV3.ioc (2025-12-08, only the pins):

Mcu.UserName=STM32H743VITx
PA0.GPIO_Label=KR
PA0.Signal=GPIO_Input
PA1.GPIO_Label=MAIN_PWR
PA1.Signal=GPIO_Output
PA10.Signal=USART1_RX
PA2.GPIO_Label=SUB_OLED_BLK_PWM
PA2.Signal=S_TIM15_CH1
PA3.Signal=S_TIM5_CH4
PA5.Signal=SPI1_SCK
PA6.GPIO_Label=BAT_ADC_EN
PA6.Signal=GPIO_Output
PA7.Signal=SPI1_MOSI
PA8.GPIO_Label=TF_DETECH
PA8.Signal=GPIO_Input
PA9.Signal=USART1_TX
PB12.GPIO_Label=NRF2_IRQ
PB12.Signal=GPIO_Input
PB13.Signal=SPI2_SCK
PB14.Signal=SPI2_MISO
PB15.Signal=SPI2_MOSI
PB2.Signal=QUADSPI_CLK
PB6.Signal=QUADSPI_BK1_NCS
PB8.Signal=I2C1_SCL
PB9.Signal=I2C1_SDA
PC0.Signal=ADCx_INP10
PC1.Signal=ADCx_INP11
PC10.Signal=SDMMC1_D2
PC11.Signal=SDMMC1_D3
PC12.Signal=SDMMC1_CK
PC2_C.GPIO_Label=CHR_STDBY
PC2_C.Signal=GPIO_Input
PC3_C.GPIO_Label=CHR_CHAR
PC3_C.Signal=GPIO_Input
PC4.GPIO_Label=OLED_RES
PC4.Signal=GPIO_Output
PC5.GPIO_Label=OLED_DC
PC5.Signal=GPIO_Output
PC8.Signal=SDMMC1_D0
PC9.Signal=SDMMC1_D1
PD0.Signal=UART4_RX
PD1.Signal=UART4_TX
PD10.GPIO_Label=NRF2_EN
PD10.Signal=GPIO_Output
PD11.Signal=QUADSPI_BK1_IO0
PD12.Signal=QUADSPI_BK1_IO1
PD13.Signal=QUADSPI_BK1_IO3
PD2.Signal=SDMMC1_CMD
PD5.GPIO_Label=OLED_BLK
PD5.Signal=GPIO_Output
PD6.GPIO_Label=DEBUG_R
PD6.Signal=GPIO_Output
PD7.GPIO_Label=DEBUG_L
PD7.Signal=GPIO_Output
PD8.GPIO_Label=NRF2_CSN
PD8.Signal=GPIO_Output
PD9.GPIO_Label=NRF2_CE
PD9.Signal=GPIO_Output
PE10.GPIO_Label=NRF1_CE
PE10.Signal=GPIO_Output
PE11.Signal=SPI4_NSS
PE12.Signal=SPI4_SCK
PE13.Signal=SPI4_MISO
PE14.Signal=SPI4_MOSI
PE15.GPIO_Label=NRF1_IRQ
PE15.Signal=GPXTI15
PE2.Signal=QUADSPI_BK1_IO2
PE9.GPIO_Label=NRF1_EN
PE9.Signal=GPIO_Output

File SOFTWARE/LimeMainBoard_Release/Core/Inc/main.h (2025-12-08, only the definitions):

#define CHR_STDBY_Pin GPIO_PIN_2
#define CHR_STDBY_GPIO_Port GPIOC
#define CHR_CHAR_Pin GPIO_PIN_3
#define CHR_CHAR_GPIO_Port GPIOC
#define KR_Pin GPIO_PIN_0
#define KR_GPIO_Port GPIOA
#define MAIN_PWR_Pin GPIO_PIN_1
#define MAIN_PWR_GPIO_Port GPIOA
#define SUB_OLED_BLK_PWM_Pin GPIO_PIN_2
#define SUB_OLED_BLK_PWM_GPIO_Port GPIOA
#define BAT_ADC_EN_Pin GPIO_PIN_6
#define BAT_ADC_EN_GPIO_Port GPIOA
#define OLED_RES_Pin GPIO_PIN_4
#define OLED_RES_GPIO_Port GPIOC
#define OLED_DC_Pin GPIO_PIN_5
#define OLED_DC_GPIO_Port GPIOC
#define NRF1_EN_Pin GPIO_PIN_9
#define NRF1_EN_GPIO_Port GPIOE
#define NRF1_CE_Pin GPIO_PIN_10
#define NRF1_CE_GPIO_Port GPIOE
#define NRF1_IRQ_Pin GPIO_PIN_15
#define NRF1_IRQ_GPIO_Port GPIOE
#define NRF1_IRQ_EXTI_IRQn EXTI15_10_IRQn
#define NRF2_IRQ_Pin GPIO_PIN_12
#define NRF2_IRQ_GPIO_Port GPIOB
#define NRF2_CSN_Pin GPIO_PIN_8
#define NRF2_CSN_GPIO_Port GPIOD
#define NRF2_CE_Pin GPIO_PIN_9
#define NRF2_CE_GPIO_Port GPIOD
#define NRF2_EN_Pin GPIO_PIN_10
#define NRF2_EN_GPIO_Port GPIOD
#define TF_DETECH_Pin GPIO_PIN_8
#define TF_DETECH_GPIO_Port GPIOA
#define OLED_BLK_Pin GPIO_PIN_5
#define OLED_BLK_GPIO_Port GPIOD
#define DEBUG_R_Pin GPIO_PIN_6
#define DEBUG_R_GPIO_Port GPIOD
#define DEBUG_L_Pin GPIO_PIN_7
#define DEBUG_L_GPIO_Port GPIOD
#define GLOBAL_SOFTWARE_VERSION		"V3.1.0"

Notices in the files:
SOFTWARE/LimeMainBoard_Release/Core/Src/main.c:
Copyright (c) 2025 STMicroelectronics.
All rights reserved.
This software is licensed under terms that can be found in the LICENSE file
